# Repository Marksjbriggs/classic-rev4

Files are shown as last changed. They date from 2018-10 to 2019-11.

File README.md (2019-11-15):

# Information

This is the design for the Classic Rev4 Nixie Clock Module

Copyright 2015-2019 Ian Sparkes

This board is published under Creative Commons CC-BY-SA

We ask for modifications and contributions to be submitted to

nixie at protonmail.com

# code

The code is available here:

https://bitbucket.org/isparkes/nixiefirmwarev1/src/master/

4 Digit code is in the directory: ardunixFade9_4_digit

6 Digit code is in the directory: ardunixFade9_6_digit

# Support

You can get support for this board at

https://www.nixieclock.biz under the "Support" section.

If you bought the board from us, support is free. If you made it yourself or bought it from someone else, we ask a support fee of $10.

# Purchase

You can get ready made PCBs and kits from 

https://www.nixieclock.biz/StoreClassic.html

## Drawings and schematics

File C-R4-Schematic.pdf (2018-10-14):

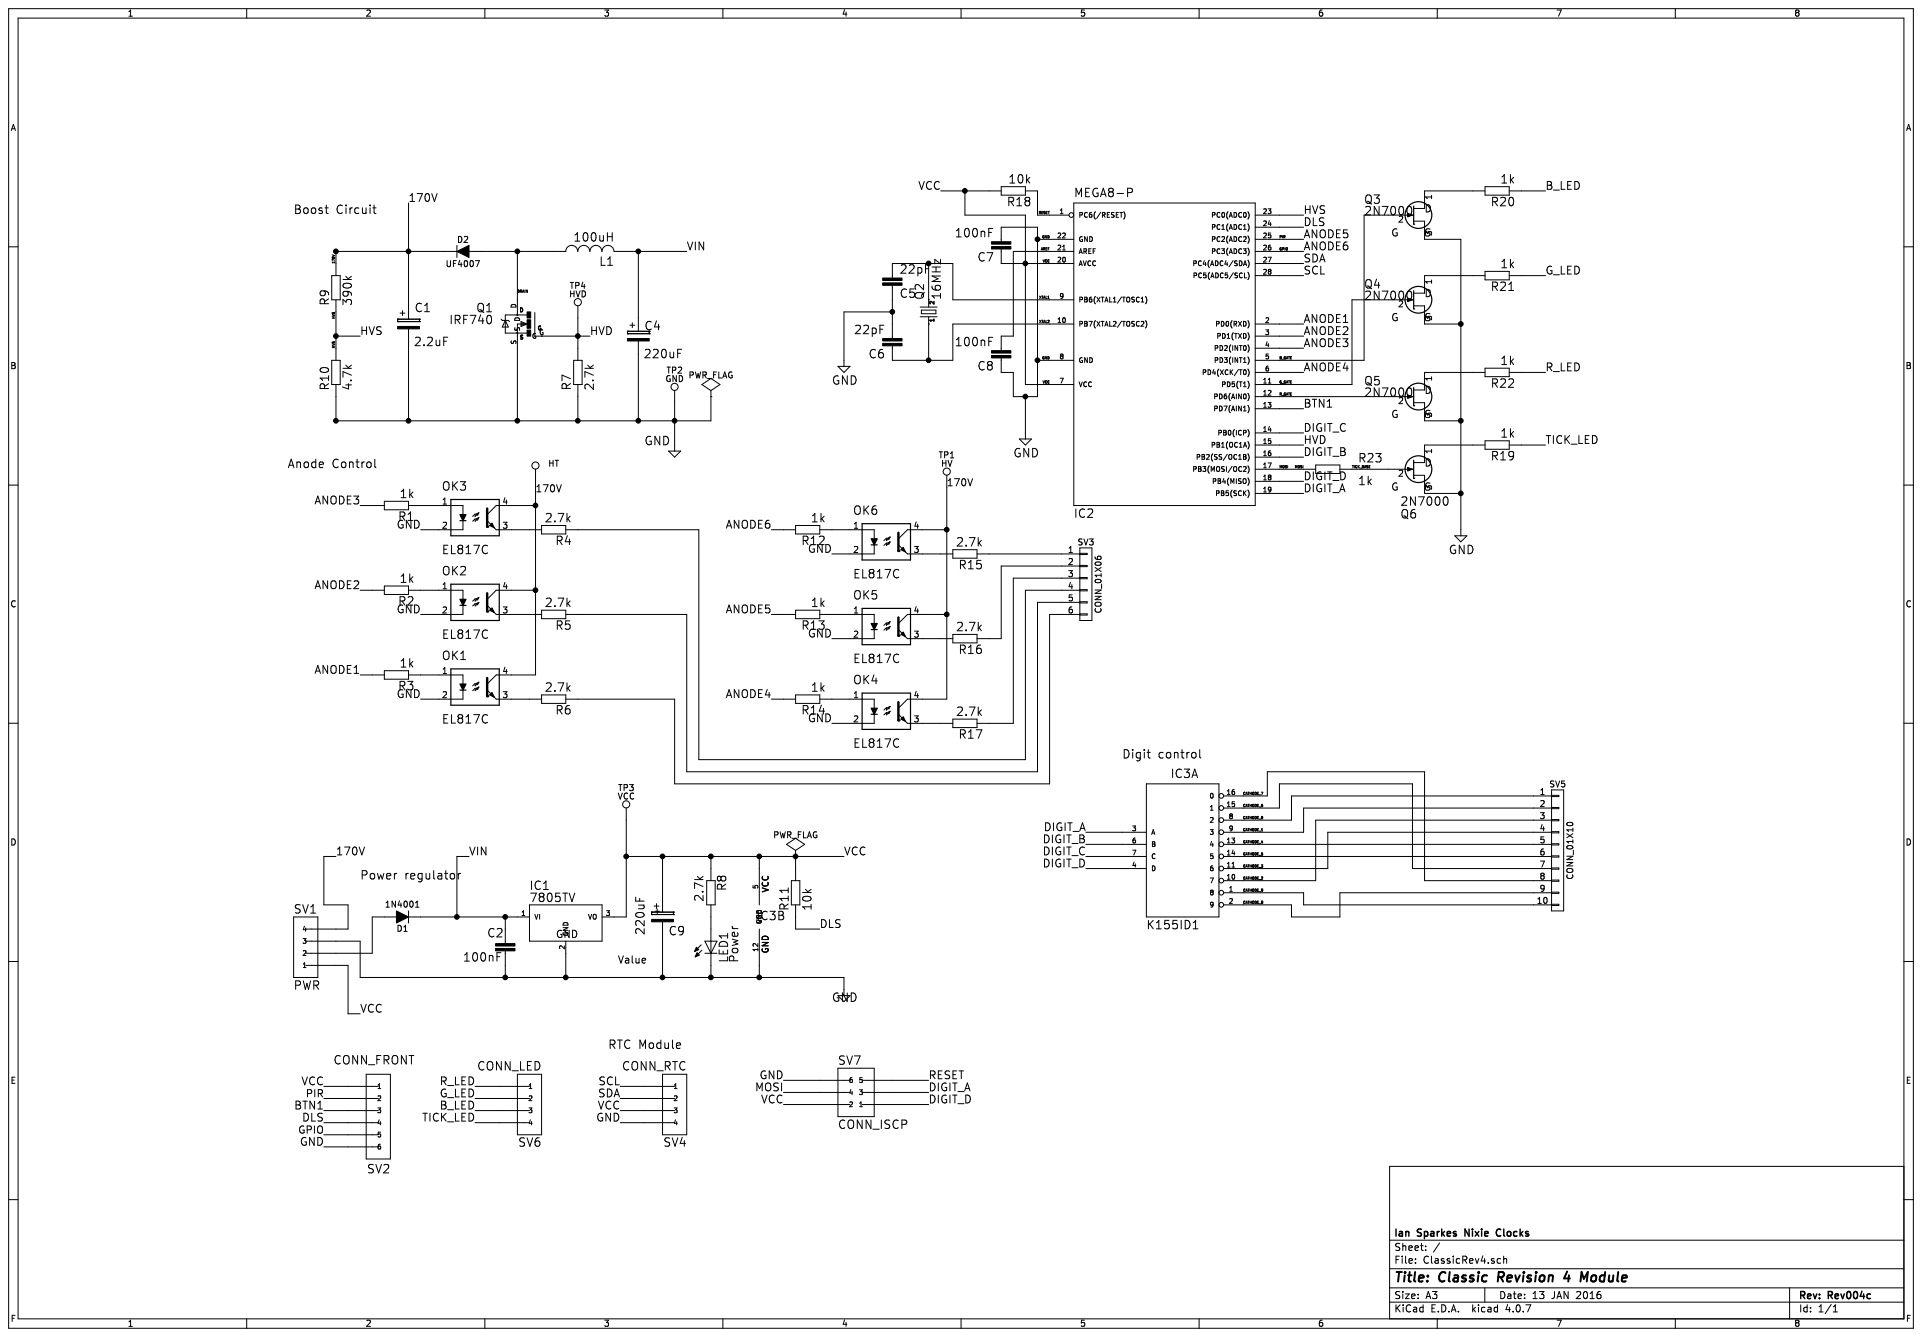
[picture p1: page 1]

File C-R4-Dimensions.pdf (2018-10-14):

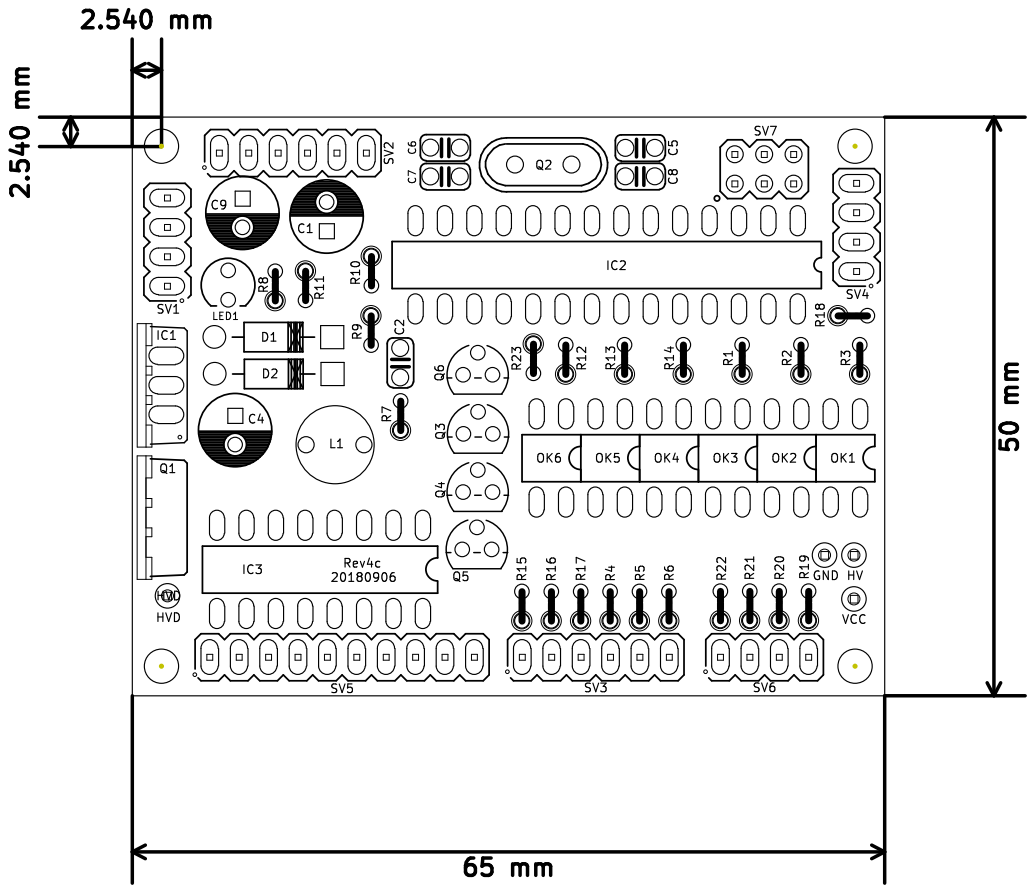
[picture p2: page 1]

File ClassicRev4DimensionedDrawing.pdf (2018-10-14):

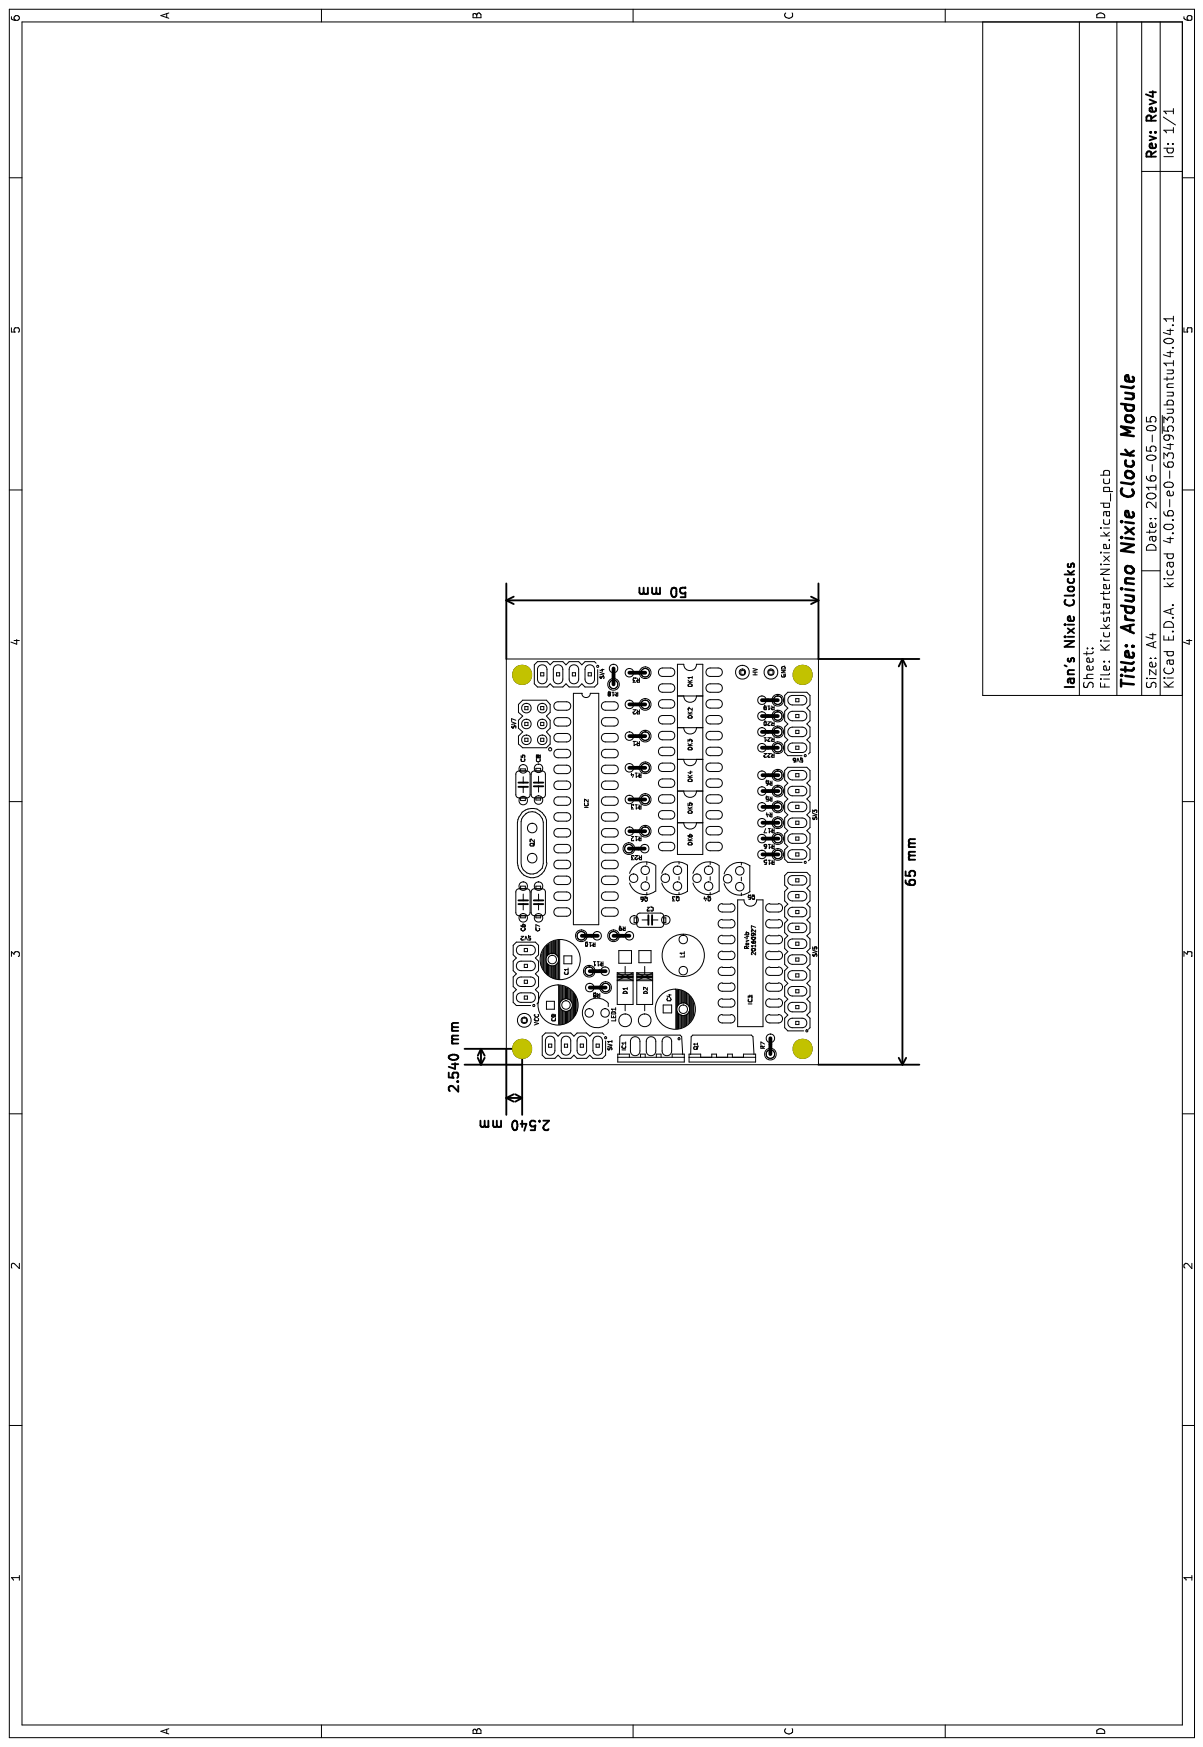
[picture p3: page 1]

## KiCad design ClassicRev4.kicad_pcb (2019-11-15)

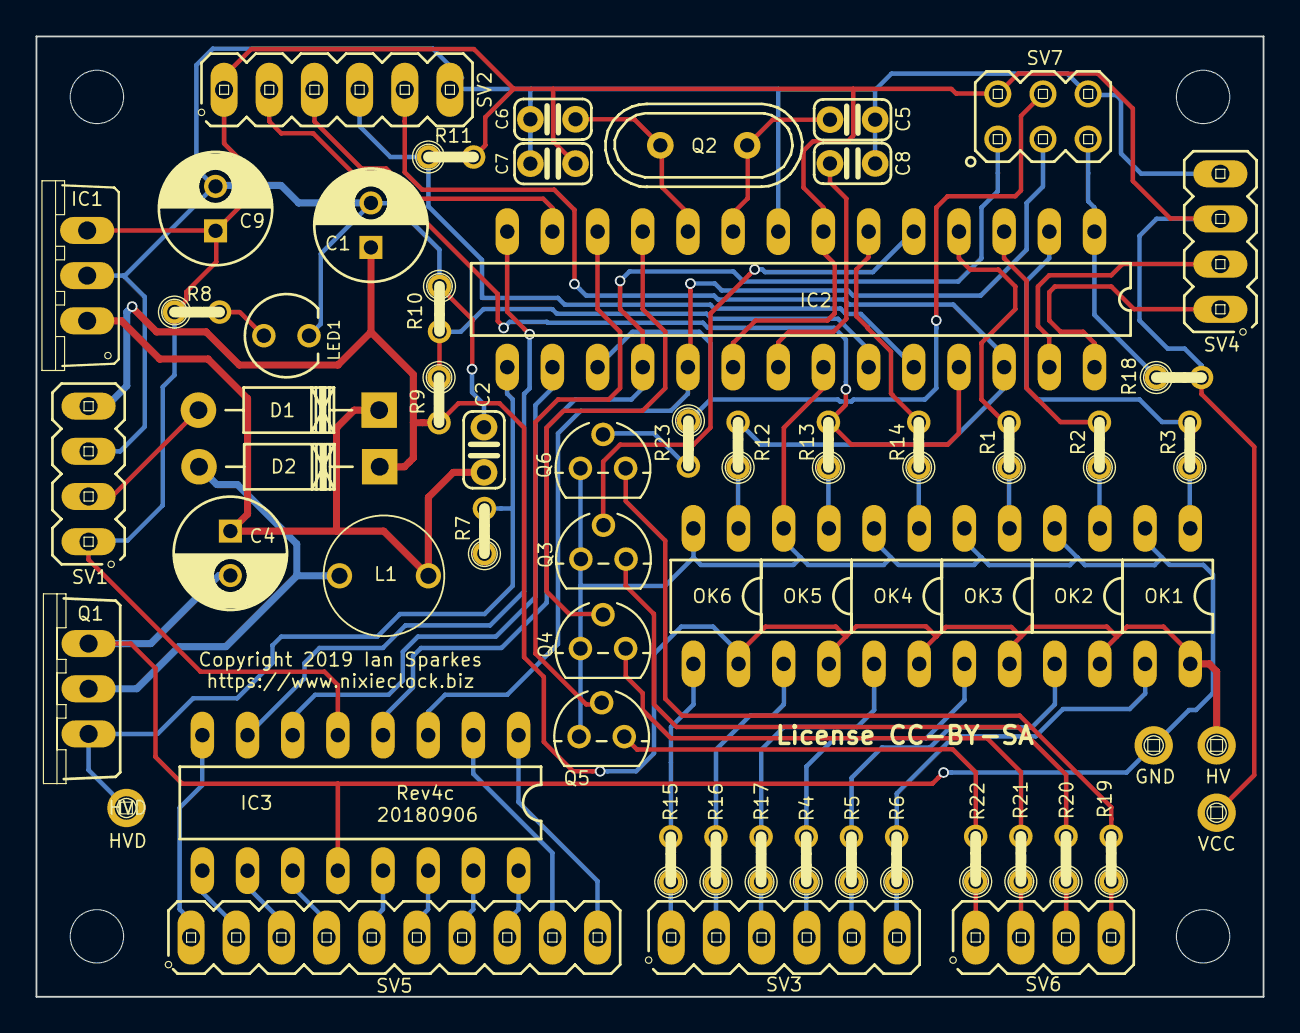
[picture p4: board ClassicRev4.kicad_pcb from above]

Board: 2 copper layers, 69.0 x 54.0 mm, 65 parts (0 on the bottom side), 68 nets.

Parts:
C1: 2.2uF; C_Radial_D6.3_L11.2_P2.5
C2, C7, C8: 100nF; C025-024X044
C4, C9: 220uF; C_Radial_D6.3_L11.2_P2.5
C5, C6: 22pF; C025-024X044
D1: 1N4001; Diode_DO-41_1N4001
D2: UF4007; Diode_DO-41_1N4001
IC1: 7805TV; 7805_TO220V
IC2: MEGA8-P; 328P_DIL28
IC3: K155ID1; 74141_DIL16
L1: 100uH; Inductor-100mH
LED1: Power; LED_3MM
MH1, MH2, MH3, MH4: MountingHole_3mm
OK1, OK2, OK3, OK4, OK5, OK6: EL817C; optocoupler-DIL04
Q1: IRF740; TRANSISTOR-POWER_TO220BV
Q2: 16MHz; Crystal_HC49-U_Vertical
Q3, Q4, Q5, Q6: 2N7000; 2N7000_TO92
R1, R2, R3, R12, R13, R14, R19, R20, R21, R22, R23: 1k; R-0207_2V
R4, R5, R6, R7, R8, R15, R16, R17: 2.7k; R-0207_2V
R9: 390k; R-0207_2V
R10: 4.7k; R-0207_2V
R11, R18: 10k; R-0207_2V
SV1: PWR; Header_MA04-1
SV2: CONN_FRONT; Header_MA06-1
SV3: CONN_01X06; Header_MA06-1
SV4: CONN_RTC; Header_MA04-1
SV5: CONN_01X10; Header_MA10-1
SV6: CONN_LED; Header_MA04-1
SV7: CONN_ISCP; Header_MA03-2
TP1: HV; TESTPAD_P1-13
TP2: GND; TESTPAD_P1-13
TP3: VCC; TESTPAD_P1-13
TP4: HVD; TESTPAD_P1-13

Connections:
/170V: C1.1, D2.1, OK1.4, OK2.4, OK3.4, OK4.4, OK5.4, OK6.4, R9.2, SV1.4, TP1.1
/ANODE1: IC2.2, R3.2
/ANODE2: IC2.3, R2.2
/ANODE3: IC2.4, R1.2
/ANODE4: IC2.6, R14.2
/ANODE5: IC2.25, R13.2, SV2.2
/ANODE6: IC2.26, R12.2, SV2.5
/AREF: C8.2, IC2.21
/BTN1: IC2.13, SV2.3
/B_GATE: IC2.5, Q3.2
/B_LED: R20.1, SV6.3
/CATHODE_0: IC3.8, SV5.1
/CATHODE_1: IC3.9, SV5.2
/CATHODE_2: IC3.10, SV5.3
/CATHODE_3: IC3.11, SV5.4
/CATHODE_4: IC3.13, SV5.5
/CATHODE_5: IC3.14, SV5.6
/CATHODE_6: IC3.15, SV5.7
/CATHODE_7: IC3.16, SV5.8
/CATHODE_8: IC3.2, SV5.9
/CATHODE_9: IC3.1, SV5.10
/DIGIT_A: IC2.19, IC3.3, SV7.3
/DIGIT_B: IC2.16, IC3.6
/DIGIT_C: IC2.14, IC3.7
/DIGIT_D: IC2.18, IC3.4, SV7.1
/DLS: IC2.24, R11.1, SV2.4
/DRAIN: D2.2, L1.1, Q1.D
/G_GATE: IC2.11, Q4.2
/G_LED: R21.1, SV6.2
/HVD: IC2.15, Q1.G, R7.2, TP4.1
/HVS: IC2.23, R9.1, R10.2
/MOSI: IC2.17, R23.1, SV7.4
/RESET: IC2.1, R18.1, SV7.5
/R_GATE: IC2.12, Q5.2
/R_LED: R22.1, SV6.1
/SCL: IC2.28, SV4.1
/SDA: IC2.27, SV4.2
/TICK_BASE: Q6.2, R23.2
/TICK_LED: R19.1, SV6.4
/VCC: C7.1, C9.1, IC1.3, IC2.7, IC2.20, IC3.5, R8.1, R11.2, R18.2, SV1.1, SV2.1, SV4.3, SV7.2, TP3.1
/VIN: C2.2, C4.1, D1.1, IC1.1, L1.2
/XTAL1: C5.2, IC2.9, Q2.2
/XTAL2: C6.1, IC2.10, Q2.1
GND: C1.2, C2.1, C4.2, C5.1, C6.2, C7.2, C8.1, C9.2, IC1.2, IC2.8, IC2.22, IC3.12, LED1.K, OK1.2, OK2.2, OK3.2, OK4.2, OK5.2, OK6.2, Q1.S, Q3.3, Q4.3, Q5.3, Q6.3, R7.1, R10.1, SV1.3, SV2.6, SV4.4, SV7.6, TP2.1
unnamed: D1.2, SV1.2
unnamed: LED1.A, R8.2
unnamed: OK1.1, R3.1
unnamed: OK1.3, R6.2
unnamed: OK2.1, R2.1
unnamed: OK2.3, R5.2
unnamed: OK3.1, R1.1
unnamed: OK3.3, R4.2
unnamed: OK4.1, R14.1
unnamed: OK4.3, R17.2
unnamed: OK5.1, R13.1
unnamed: OK5.3, R16.2
unnamed: OK6.1, R12.1
unnamed: OK6.3, R15.2
unnamed: Q3.1, R20.2
unnamed: Q4.1, R21.2
unnamed: Q5.1, R22.2
unnamed: Q6.1, R19.2
unnamed: R4.1, SV3.4
unnamed: R5.1, SV3.5
unnamed: R6.1, SV3.6
unnamed: R15.1, SV3.1
unnamed: R16.1, SV3.2
unnamed: R17.1, SV3.3

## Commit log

2018-10-14 Initial version Classic Rev4b
    [ClassicRev4.kicad_pcb, ClassicRev4.sch]
2018-10-14 Initial commit Classic Rev4c
    [ClassicRev4.kicad_pcb, ClassicRev4.sch]
2018-10-25 Correct values and divide more logically
    [ClassicRev4.sch]
2019-01-18 KiCad 5
    [ClassicRev4.kicad_pcb, ClassicRev4.sch]
2019-11-12 Set voltage
    [ClassicRev4.sch]
2019-11-15 Add copyright and license notices
    [ClassicRev4.kicad_pcb]

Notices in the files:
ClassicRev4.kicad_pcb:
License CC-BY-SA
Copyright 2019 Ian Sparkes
